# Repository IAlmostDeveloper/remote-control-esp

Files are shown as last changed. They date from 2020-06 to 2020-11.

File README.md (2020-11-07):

# remote-control-esp

## Прошивка для контроллера в рамках проекта RemoteControl

#### Контроллер выполняет роль устройства, передающего получаемый сигнал приборам, управляемым с помощью инфракрасных ДУ пультов, что позволяет использовать его и приложение-клиент вместо оригинального пульта. 

#### Также контроллер имеет функцию приемника, позволяя добавлять в приложение-клиент кнопки оригинального пульта.

### Зависимости для сборки прошивки:
- ESP8266 (https://github.com/esp8266/Arduino)
- ArduinoJson 5
- IRRemoteESP8266
- PubSubClient

Все библиотеки устанавливаются через менеджер библиотек в Arduino IDE

### Инструкция по сборке:
- Собирать как проект в среде разработки Arduino IDE
- Необходимо установить утилиту ESP8266FS для записи файловой системы в контроллер, а затем загрузить файловую систему через Arduino IDE
- Как загрузить файловую систему в esp8266: http://digitrode.ru/computing-devices/mcu_cpu/2186-ustanavlivaem-zagruzchik-faylovoy-sistemy-esp8266-s-pomoschyu-arduino-ide.html 
### 
## Cхема устройства:



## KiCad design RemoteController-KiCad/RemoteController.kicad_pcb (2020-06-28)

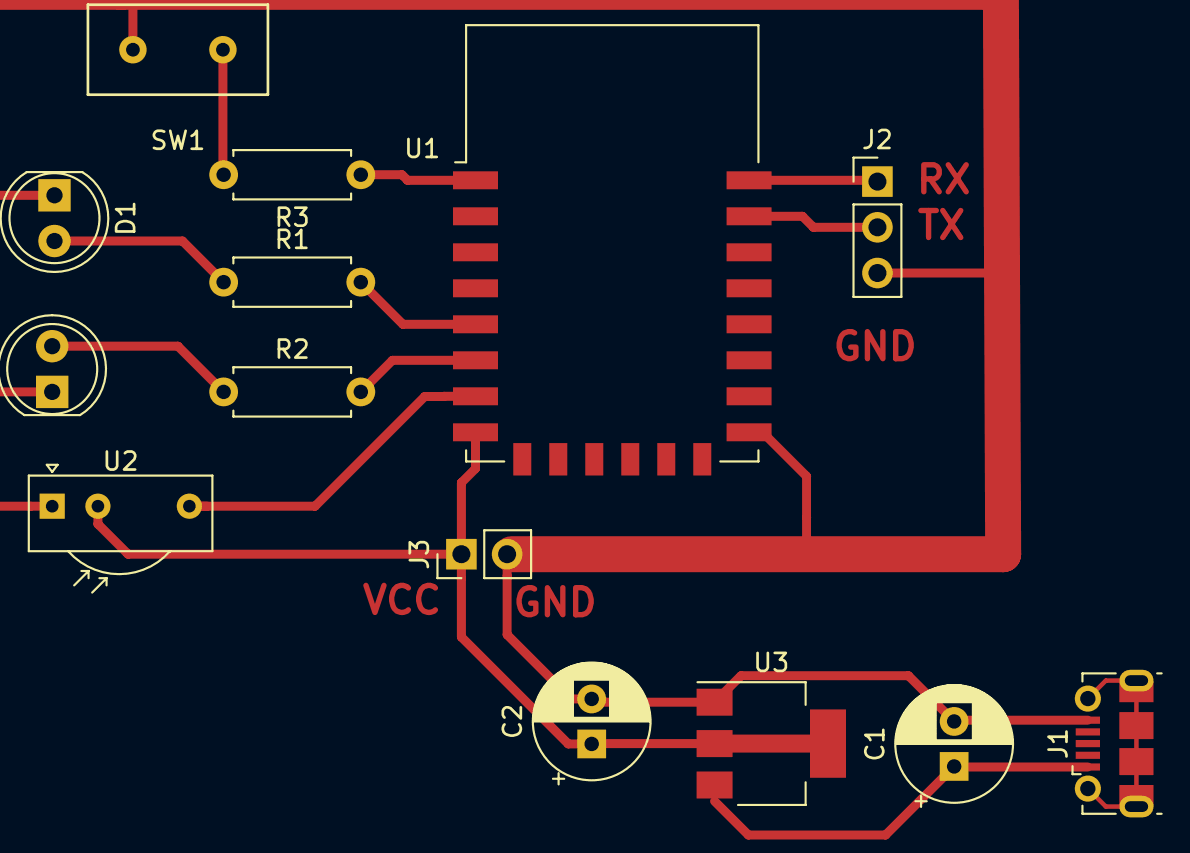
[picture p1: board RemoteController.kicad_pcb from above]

Board: 2 copper layers, 14 parts (0 on the bottom side), 12 nets.

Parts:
C1, C2: 100mF; CP_Radial_D6.3mm_P2.50mm
D1: IR_LED; LED_D5.0mm
D2: LED; LED_D5.0mm
J1: USB_B_Micro; USB_Micro-B_Molex-105017-0001
J2: Conn_01x03; PinHeader_1x03_P2.54mm_Vertical
J3: ext.power; PinHeader_1x02_P2.54mm_Vertical
R1, R2: 220 Ohm; R_Axial_DIN0207_L6.3mm_D2.5mm_P7.62mm_Horizontal
R3: 12k; R_Axial_DIN0207_L6.3mm_D2.5mm_P7.62mm_Horizontal
SW1: SW_DPST_x2; Button Tactile 5 MM
U1: ESP-12E
U2: TSOP1738; Vishay_CAST-3Pin
U3: AMS1117-3.3; SOT-223-3_TabPin2

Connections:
GNDD: C1.2, C2.2, D1.1, D2.1, J1.5, J2.3, J3.2, SW1.1, U1.15, U2.1, U3.1
unnamed: C1.1, J1.1, U3.3
unnamed: C2.1, J3.1, U1.8, U2.2, U3.2
unnamed: D1.2, R1.1
unnamed: D2.2, R2.1
unnamed: J2.1, U1.22
unnamed: J2.2, U1.21
unnamed: R1.2, U1.5
unnamed: R2.2, U1.6
unnamed: R3.1, U1.1
unnamed: R3.2, SW1.2
unnamed: U1.7, U2.3

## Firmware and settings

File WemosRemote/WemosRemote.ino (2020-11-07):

#include "WemosRemote.h"

void callback(char* topic, byte* payload, unsigned int length) {
  Serial.print("Message arrived [");
  Serial.print(topic);
  Serial.println("]");
  String encoding;
  String currentTopic = String(topic);
  if (currentTopic.endsWith("Controller")) {
    if (currentTopic.endsWith("/RC5Controller"))
      encoding = "RC5";
    if (currentTopic.endsWith("/NECController"))
      encoding = "NEC";
    unsigned long code = getCodeFromPayload(payload, length);
    sendCode(code, encoding);
  }
  if (currentTopic.endsWith("Controller/delay")) {
    const size_t capacity = JSON_OBJECT_SIZE(3) + JSON_ARRAY_SIZE(2) + 60;
    DynamicJsonBuffer jsonBuffer(capacity);
    JsonObject& root = jsonBuffer.parseObject(payload);
    if (!root.success()) {
      Serial.println(F("Parsing failed!"));
      return;
    }
    if (currentTopic.endsWith("/RC5Controller/delay"))
      encoding = "RC5";
    if (currentTopic.endsWith("/NECController/delay"))
      encoding = "NEC";
    String rawCode = root["code"].as<String>();
    char arr[rawCode.length() + 1];
    rawCode.toCharArray(arr, rawCode.length() + 1);
    unsigned long code = strtol(arr, NULL, 16);
    int delayTime = root["delay"].as<int>();
    Serial.println(code);
    Serial.println(delayTime);
    sendCodeWithDelay(code, encoding, delayTime);
  }
  if (currentTopic.endsWith("/receive")) {
    sendReceivedCode(payload, length);
  }
}

void setup() {
  pinMode(ledPin, OUTPUT);
  pinMode(resetPin, INPUT_PULLUP);
  digitalWrite(ledPin, 1);
  irsend.begin();
  Serial.begin(115200);
  delay(10);
  Serial.println("\n");
  SPIFFS.begin();
  mqtt_server = convertToCharArray(getStringFromFile("/mqttaddress.txt"));
  mqtt_port = getStringFromFile("/mqttport.txt").toInt();
  mqtt_user = convertToCharArray(getStringFromFile("/mqttusername.txt"));
  mqtt_pass = convertToCharArray(getStringFromFile("/mqttpassword.txt"));
  ssid = convertToCharArray(getStringFromFile("/wifissid.txt"));
  pass = convertToCharArray(getStringFromFile("/wifipass.txt"));
  server.begin();
  server.on("/", handleRoot);
  server.on("/led", blinkLed);
  server.on("/mqtt", mqttSetup);
  server.on("/wifi", wifiSetup);
  server.on("/submit/mqtt", mqttSubmit);
  server.on("/submit/wifi", wifiSubmit);
}
unsigned long lastMsg = 0;
void loop() {
  server.handleClient();
  connectToWiFi();
  checkForReset();
  if (WiFi.status() == WL_CONNECTED) {
    if (!client.connected()) {
      Serial.print("Connecting to MQTT server ");
      Serial.print(mqtt_server);
      Serial.println("...");
      if (connectToMQTT()) {
        WiFi.mode(WIFI_STA);
        WiFi.softAPdisconnect(false);
        WiFi.enableAP(false);
        digitalWrite(ledPin, 0);
      }
    }
    if (client.connected()){
      client.loop();
      if(millis()-lastMsg>30000){
        lastMsg = millis();
        Serial.print("Publish message: alive");
        client.publish("remoteControl/devices/1/alive", "1");
      }
    }
    else
      digitalWrite(ledPin, 1);
  }
  else
    digitalWrite(ledPin, 1);
}

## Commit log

2020-06-27 add schematic
2020-06-28 added KiCad files
    [RemoteController.dsn, RemoteController.kicad_pcb, RemoteController.sch]
2020-09-30 Все исходники лежат здесь
    [RemoteController.dsn, RemoteController.kicad_pcb, RemoteController.sch]
